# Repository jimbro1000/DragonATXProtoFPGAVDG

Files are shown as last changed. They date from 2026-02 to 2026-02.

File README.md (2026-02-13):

# Dragon ATX Prototype FPGA VDG

This repository contains the KiCad project files
to produce the VDG component board for my
ATX Prototype backplane.

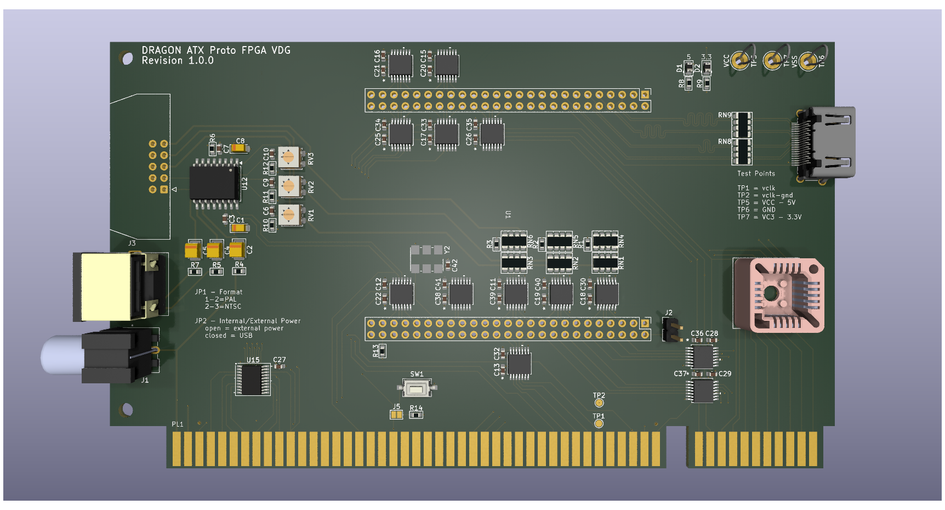
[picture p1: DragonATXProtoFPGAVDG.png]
Render of PCB top


This design requires the ATX backplane board in order 
to operate
See https://github.com/jimbro1000/DragonATXProto

## Notes

Revision 1 includes a more modern RGB fed modulator
design that removes a significant problem in the 
form of the old LM1889 modulator. The board also
provides the mounting points for the various mezzanine
boards that have been previously developed. If the
mezzanine option is to be used the rest of the card
should be left unpopulated

This design has been completed using KiCad 9. Earlier
versions of KiCad are not compatible

## Memory Map

| Address Range | Usage | Notes |
|:--- |:----- |:----- |
| $0000 - $7FFF | Lower 32K RAM page | Can be remapped to the upper 32K using P1 under RAM/ROM memory map type |
| $8000 - $9FFF | Lower system ROM (R0) | The last 16 bytes are mapped to $FFF0 - $FFFF |
| $A000 - $BFFF | Upper system ROM (R1) | |
| $C000 - $FF00 | External ROM (R2) | |
| $C000 - $FF00 | Upper 32K RAM page | Under RAM only memory map type |
| $FF00 - $FFEF | SAM registers and Peripheral IO |
| $FF00 - $FF1F | PIA 0 & Serial port |
| $FF20 - $FF23 | PIA 1 |
| $FF24 - $FF27 | PIA 1b | video expansion slot |
| $FF28 - $FF2F | PIA 1c and 1d | audio expansion slot |
| $FF30 - $FF37 | PIA 1e and 1f | expansion slot 3 |
| $FF38 - $FF3F | PIA 1g and 1h | expansion slot 4 |
| $FF40 - $FF5F | PIA 2 | external |
| $FF60 - $FFBF | reserved |
| $FF90 | Set compatible mode | bit 7 (1) |
| $FF91 | Set task id | bits 0..2 (2)(3) |
| $FF92 | IRQ control bits | (4) |
| $FF93 | FIRQ control bits | (4) |
| $FF94 | MSB of timer |
| $FF95 | LSB of timer |
| $FFA0 | Select RAM paging register | Registers are selected for the current task only |
| $FFA1 | Upper byte of page register | |
| $FFA2 | Lower byte of page register | Writing to the lower byte commits changes to the selected register |
| $FFC0 - $FFDF | SAM |
| $FFE0 - $FFEF | reserved |
| $FFF0 - $FFFF | CPU vectors |

1. Compatibility mode forces the SAMx to behave as an original MC6883 SAM. Setting the bit to 1 turns compatibility on, clearing the bit enables the additional SAMx features. The other bits of the register are unused.

2. Tasks are identified by 3 bits - bits 0 to 2, 000 = task 0 (typically reserved for the operating system), 001 = task 1, 010 = task 2, 011 = task 3, 100 = task 4. (task ids 101 and 110 are reserved for VDG and library pages, 111 is associated with unallocated pages).

3. Bit 5 is used to specify the resolution of the timer, clearing the bit used a slow timer, setting the bit uses a fast timer.

4. The SAMx can generate interrupts according to the bit masks set for IRQ and FIRQ. The only bit defined at the moment is bit 5 and is triggered by the timer (counting down to 0). If the bit is cleared the SAMx will not generate an interrupt, if set the interrupt will be generated against the chosen interrupt line ($FF92 for IRQ, $FF93 for FIRQ). It is currently possible to specify an interrupt on both lines, in this situation FIRQ will be used.

5. In the RAM type memory map the paging for any of the registers can be set to bank of the ROM, in the RAM/ROM type memory map the R0 and R1 blocks need to behave differently. R0 at $8000 is mapped in 4 blocks to $00000 of the ROM by default, R1 is mapped to $A000 in 4 blocks at $02000. R2 is bound exclusively to the cartridge port ROM space at $C000, there is no mechanism to map this to a ROM bank. In RAM mode R2 can be mapped to a RAM or ROM bank but if a cartridge is fitted the paging is ignored and the cartridge ROM is used instead.

### Expanded Memory

| Address Range | Notes |
|:--- |:----- |
| $000000 - $00FFFF | CPU addressable range |
| $000000 - $01FFFF | VDG addressable range |
| $000000 - $1FFFFF | Maximum onboard paged RAM |
| $000000 - $080000 | Maximum onboard paged ROM |

## Design

Unlike previous iterations that attempt to simply
replicate the original 6847 using CPLD hardware, this
design is aimed at a full upgrade and replacement for 
the 6847 and 6883. By combining the functionality of
the two chips are significant saving in complexity is
achieved. There is no longer a requirement to 
artificially synchronise the video against the CPU
clock cycle, this is inherent as the video clock is
tied directly to the cpu clock.

## SAM upgrades

The SAM replacement is based around the work done by
Ciaran Anscomb to upgrade the SAM to include RAM paging.
His design extended to 512KB which, while "adequate", 
is wasteful of the target FPGA device which includes
16MB of RAM. Of that 16MB only 2MB is directly accessed
as a single block. The 2MB is 16bit wide (technically 4MB)
but accessing both halves of the RAM adds extra complexity
to the read/write cycle, just using one half is definitely
simpler.

### SAM Registers ###

As a result of the SAM having full access to the databus the
internal registers can now be fully programmed with a single
write operation (or per bit if required). The registers are
expanded as necessary, for example the video base address is
extended to allow addressing of a much larger memory space,
and the introduction of new registers for process and memory
mapping.

#### Programmable Registers ####

| Register | Size | Usage |
| --- | ---- | ----- |
| V | 3 bits | Video addressing mode - 4 bits in expanded mode - the extra bit is ignored unless the VDG compatibility mode is disabled |
| F | 7 bits | Video base addressing multiples of 512 bytes - 8 bits in expanded mode, after a vertical sync the VDG address counter bits 9 - 15 are loaded with the value held in F, the lower 8 bits are set to 0. In expanded mode bits 9-16 are loaded from F |
| P | 1 bit | RAM/ROM mode page register |
| R | 2 bits | CPU speed control |
| M | 2 bits | Used to define Memory size in original SAM, unused here |
| TY | 1 bit | Memory Map Type |

#### Internal Registers

| Register | Size | Usage |
| --- | ---- | ----- |
| C | 7 bits | DRAM refresh counter - unused here |
| B | 16 bits | VDG address counter - 17 bits in expanded mode |
| N0..4x8 | 9 bits | Page Allocation Table (1) |
| NVx16 | 9 bits | Video Page Allocation Table (2) |
| Ox256 | 3 bits | Page Owner Table (3) |
| T | 3 bits | Current Task ID |
| VL | 1 bit | Video Page Lock (4) |

1. Each task has a set of 8 registers, each 9 bits in length. The MSB of each indicates
if the value is referencing RAM (0) or ROM (1). Each register defines an 8K address window
and what page of memory it is mapped to. Only one set of N registers is addressable at any
time dependent on the current task ID.

2. The Video "task" has its own set of page allocation registers and this extends to a 
total addressable space of 128K. The Video page registers are accessible to all tasks unless
the VL bit is set.

3. Each RAM page has a 4 bit identifier associated with, the value equates to one of
the task ids.

4. The Video Page lock restricts access to the video page registers to task id 0 (supervisor).
When set any attempts to modify the video page registers will be ignored.

### Memory Paging ###

The upgraded SAM provides MMU capabilities, both paging and process (page protection). With 256 8K pages in the address
space and each page can be allocated to RAM or ROM. Each process has its own page map.

Processes are either:

1. supervisor  
2. display
3. library (shared)
4. user process 1
5. user process 2
6. user process 3
7. user process 4

The shared process and display are used purely for identification of shared pages.

#### Display Process ####

The display process is used only for read operations by the VDG side of the clock cycle. The same pages can
be shared with the supervisor or a user process.

### Paging ###

Each process has its own map of 8K pages composed into the 64K memory space available directly to the CPU. The
only exception to this is the display process which has its own 128K memory space and is addressed only by the
VDG in this manner.

Each page has a permissions byte associated with it. The page is either unallocated (and can be acquired by any
process), or owned by one of the seven process ids. The display and library process pages are an exception and
can be shared between multiple processes.

The MMU maintains a page allocation table for all 256 available pages. Each process has its own address
translation map, only one map is presented to the CPU at a time, with the CPU address register translated
into the larger MMU address space.

### Rom Paging ###

Further to the available RAM pages the address map can reference pages from the ROM space. ROM pages are always
shared.

#### Rom Mapping At Cold Start ####

The MMU will always allocate the last page of the supervisor address space to the last ROM page to cover
the CPU vectors. The last ROM page should also include the bootstrap code to set the host into an operational
state.

At warm start the host will enter the supervisor process. Holding the host in reset for 2 seconds will
be treated as a cold start.

### Blitter ###

The blitter provides out-of-process memory copy in one of five operations:

1. Full page copy (8K copy from one page to another)
2. Continuous block copy (within process address space)
3. Shaped to continuous (within process address space)
4. Continuous to shaped (within process address space)
5. Shaped to shaped (within process address space)

All operations are defined by an origin, destination and byte length (maximum is 8K)

Shaped operations have two further parameters - width and gap. The width defines how many bytes in a row
are copied and the gap the number of bytes to skip to the next run of bytes

Copying can only be performed between pages allocated to the initiating process

Only a single blit operation can be performed at a time, all operations can be queued

The blit operates at the highest clock speed achievable by the RAM and SAM. Nominally this is 166MHz with a 3 cycle 
latency, the SAM operates at 28.6MHz and each byte copy takes 3 cycles. Effectively this means a copy rate of
8 bytes per CPU clock cycle (using interleaved access between CPU, VDG and Blitter) at regular 0.89MHz CPU
clock speeds. Running at a faster CPU speed would reduce the available slots for blit operations

The number of cycles for the blitter will be adjusted to suit the cpu and vdg clock speeds

A maximum copy speed can be achieved by halting the CPU and timing the blit start to the end of the vertical
display viewport. The slice allocation will reallocate CPU and VDG portions to the blitter - the result is
lightning fast block copy of ram. Page copy can run faster as it is guaranteed contiguous on both sides
meaning 64 bytes per copy cycle instead of 8 bytes. That is 128 CPU cycles (equivalent) to copy 8K at
page copy, 1024 cycles at shaped copy speeds but at the regular 0.895MHz that is still 0.001s to copy a
full 8K - in reality a shaped copy is likely to be much less than 8K in length. A regular high-res
screen is just 6K...

## VDG upgrades

The default operation mode for the VDG is full compatibility with the original MC6847. In practical
terms this means fixed display palettes (although these could still be modified through HDL source) and
standard resolutions.

With compatibility mode enabled all of the VDG control is as per the original device - external input for
Alpha/Semi, Alpha/Graphic, Graphic Mode, Inverse, Colour Set and Internal/External

With compatibility mode disabled the VDG expands control to a wide set of registers in the new
device (operated through the SAM for memory configuration and direct through a new memory
mapped device for mode). The default modes are still present but can be modified to suit, or
a new set of display modes can be used.

### VDG Registers

The upgraded VDG exists in mapped memory space, occupying 16 bytes. These form a set of registers
controlling how the video operates.

0. Video Mode Control - 8 bit flags for enabling features
1. Zero RAM Mode - left byte
2. Zero RAM Mode - right byte
3. Zero RAM Mode - palette
4. Palette - register select (0-47)
5. Palette - register data
6. Geometry - register select (0-7)
7. Geometry - register data
8. Sprite - sprite id select
9. Sprite - register select
10. Sprite - register data
11. Tile - tile id select
12. Tile - register select
13. Tile - register data
14. Counter - register select
15. Counter - register data

#### Video Mode Control

Bit 7 controls video display format, 1 = NTSC, 0 = PAL

Bit 6 controls the use of zero mode, 1 = enabled, 0 = disabled. Zero mode
is a zero ram mode that simply uses 2 static bytes of data per row, set 
using the zero ram mode registers.

Bit 5 enables tile mode. This is ignored in compatibility mode.

Bit 4 enables sprites. This is ignored in compatibility mode.

Bit 3 enables zero mode as an overlay. In this state the background colour is
always transparent.

Bit 2 enables the extended graphic modes. This is ignored in compatibility
mode.

Bit 1 is reserved for future use.

Bit 0 controls compatibility. 1 = extended options enabled, 0 = 6847
compatible.

#### Zero RAM Mode

Zero RAM mode operates without the need to load any data from RAM, combined
with a suitable ROM image this means the host system can display useful
diagnostic data without the need for working RAM. Zero RAM can also be 
enabled as an overlay over other display modes.

In Zero mode the display resolution is 16 pixels wide. The left hand side
of the display is register 1, the right hand side is register 2.

Register 1 is the first 8 bits of each row, the same data is displayed
vertically for the entire viewport unless changed mid-frame. Register is the final
8 bits of each row with the same behaviour vertically.

Register 3 controls the colour of the display, the first 4 bits define the
foreground, the last 8 bits define the background. In overlay mode the background
is always transparent.

The colours are each 4 bit TTL RGB with half bright. In the case of black the half
bright equivalent is a darker shade of grey than white with half bright.

#### Palette Control

The VDG supports 24 different programmable entries in its palette. Each one is 12 bits
of RGB and require two palette registers to access each one. Even palette registers represent 
the upper 4 bits (red) of each entry, odd palette entries represent the lower 8 bits (green and
blue) of each entry.

The first palette register (4) selects which palette entry is being referenced. With two
registers per entry the value must be multiplied by two for each entry.

The second palette register (5) defines the data of the selected palette entry.

#### Geometry Control

In the extended modes the display geometry can be modified, significantly increasing the
flexibility of thos modes.

VDG Register 6 selects which of the geometry registers is active. VDG Register 7 accesses 
the value of each.

0. Upper 2 bits of the viewport X position on screen.
1. Lower 8 bits of the viewport X position.
2. Upper 1 bit of the viewport y position.
3. Lower 8 bits of the viewport y position.
4. Viewport width (in bytes, 0-63).
5. Viewport height (in rows, 0-255).
6. Upper 1 bit of the display height (in rows).
7. Lower 8 bits of the display height.

More geometry registers may be added as new features are introduced.

#### Sprite Control

Sprites are relatively complex objects in this system. Each sprite Id can be a graphic
definition, or it can be a path object that sets how the sprite moves

VDG Register 8 selects which sprite Id is active, VDG Register 9 selects the address of the object
data. Each sprite object can be up to 255 bytes long.

VDG Register 10 access the data of the object.

#### Tile Control

Tiles are handled in much the same way as sprites for the purposes of defining them.

VDG Register 11 selects which tile Id is referenced (0-255). VDG Register 12 sets
the address within the selected tile object. VDG Register 13 accesses the tile data at
the given address.

#### Counters

A small number of counters can be defined to automatically trigger actions based on
the row or column of the current display frame.

VDG Register 14 selects which counter register is active. VDG Register 15
accesses the data for the selected counter.

### Display Layers

The display presented to the screen is composed of a series of layers.

Top most are sprites, these always have a transparency and appear over all
other graphical detail.

The next layer down is the "regular" bitmap graphic mode. If no other layers
are enabled the "0" colour will be visible, otherwise it will be transparent.

Below the bitmap mode lies the zero mode. As with the bitmap mode if tile mode
is not enabled the background colour is visible, otherwise it will be transparent.

The lowest layer is the tile mode. This has no transparency and every position
on the display must have a tile.

The composition of layers in this way offers the maximum flexibility from the
capabilities of the enhanced VDG.

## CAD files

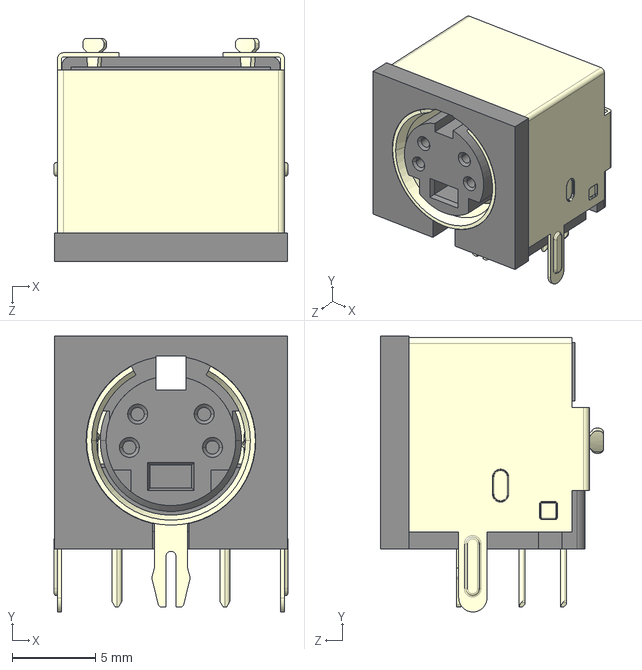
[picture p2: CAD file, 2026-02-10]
Library.3dModels/MD-40SM.step
14.1 x 16.6 x 13.4 mm

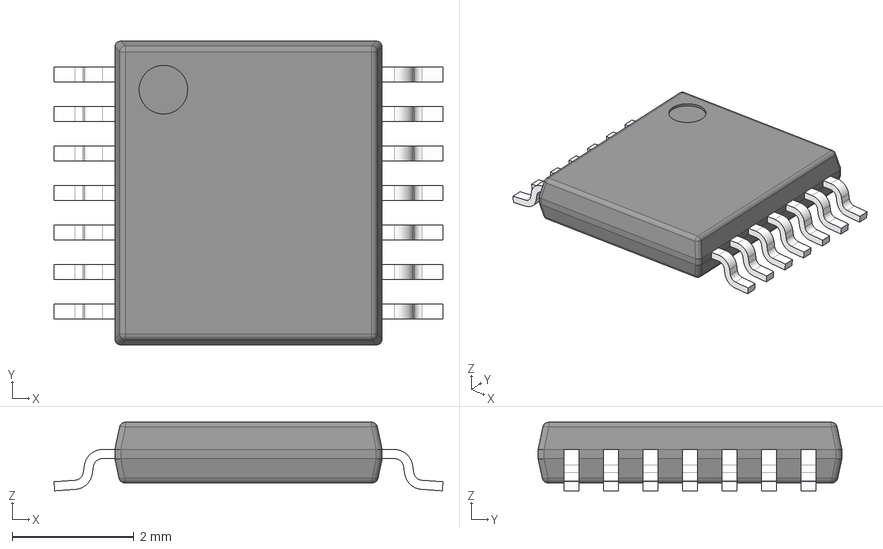
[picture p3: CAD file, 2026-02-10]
Library.3dModels/PW0014A.stp
6.40 x 5.00 x 1.13 mm
BODY-TSSOP
LEAD-TSSOP x 14
PIN1

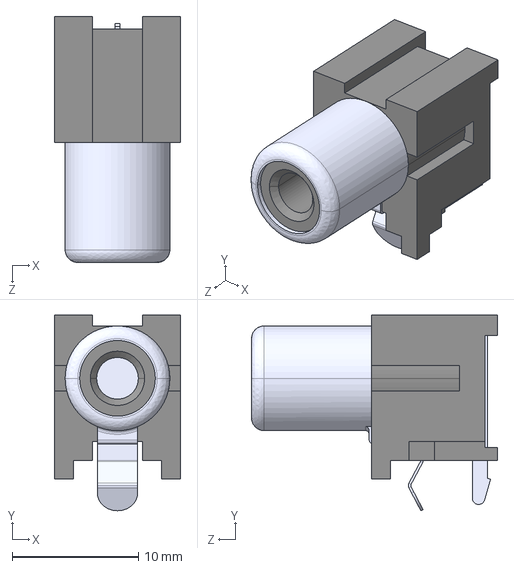
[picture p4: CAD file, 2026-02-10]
Library.3dModels/RCJ-041.step
10.0 x 15.5 x 19.5 mm

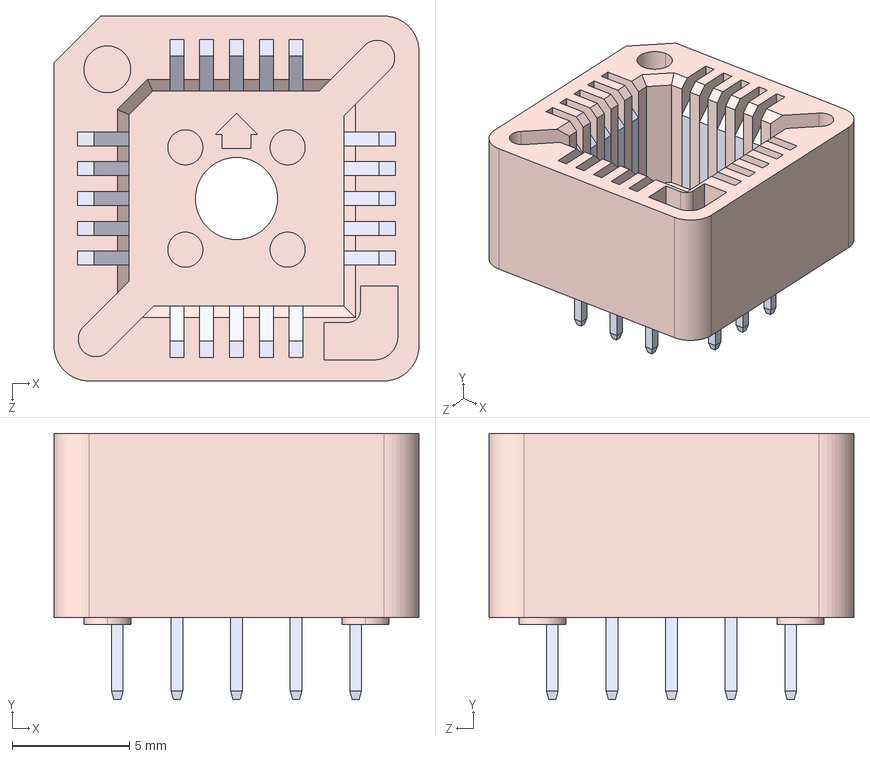
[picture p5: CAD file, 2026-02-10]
Library.3dModels/PLCC-20-R.STEP
15.6 x 11.4 x 15.6 mm

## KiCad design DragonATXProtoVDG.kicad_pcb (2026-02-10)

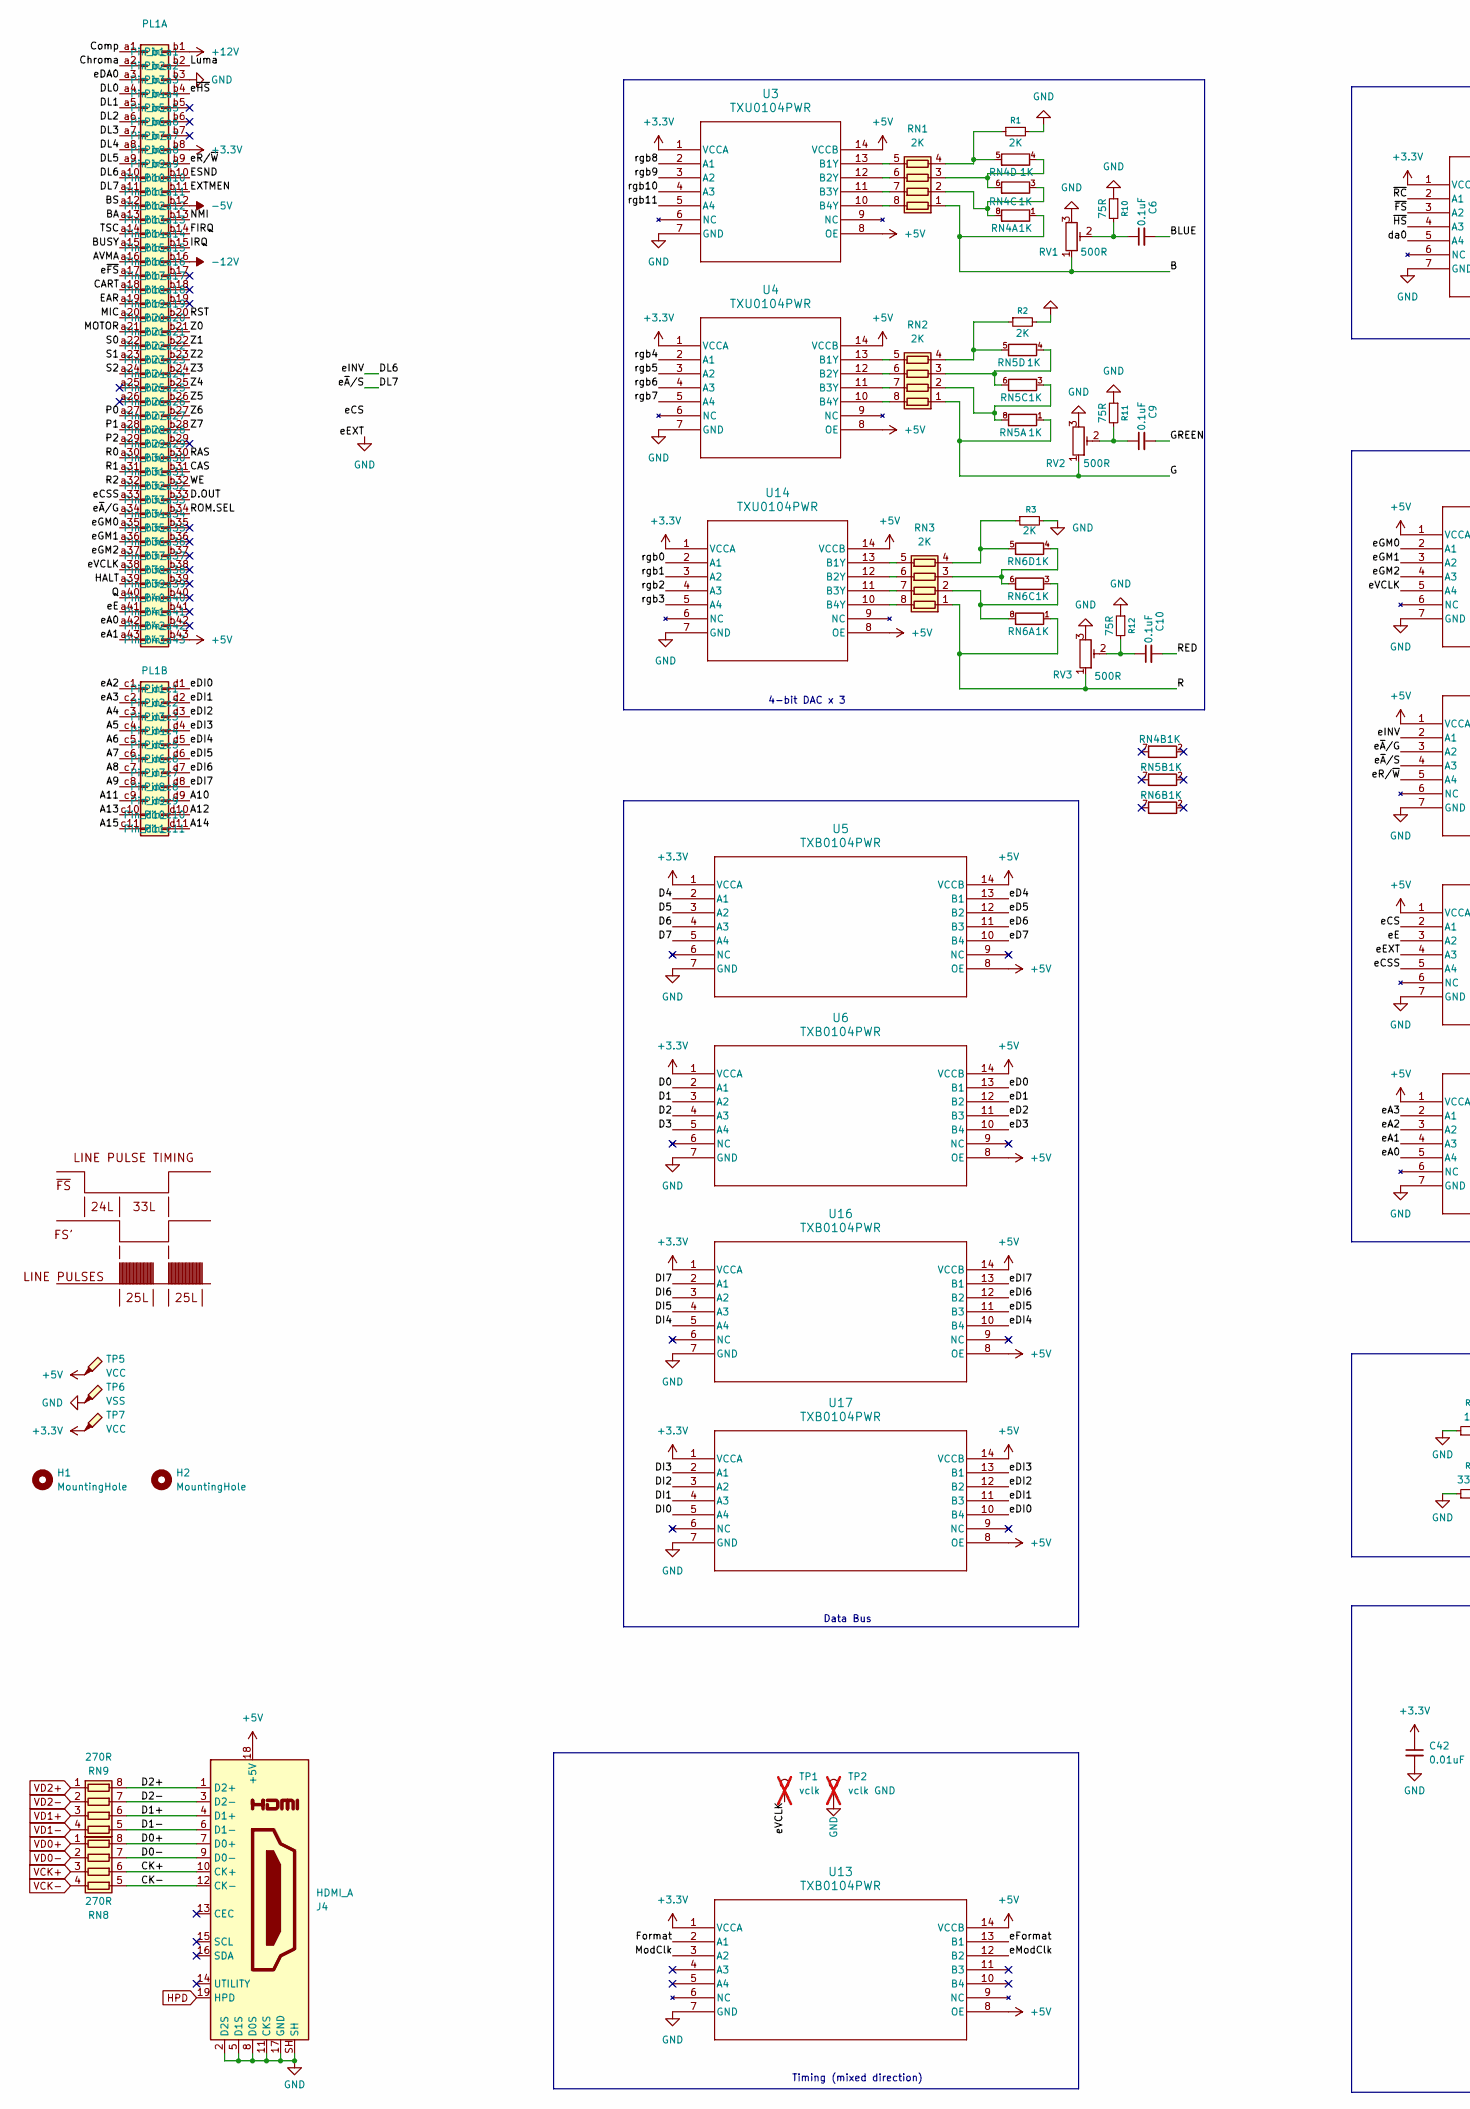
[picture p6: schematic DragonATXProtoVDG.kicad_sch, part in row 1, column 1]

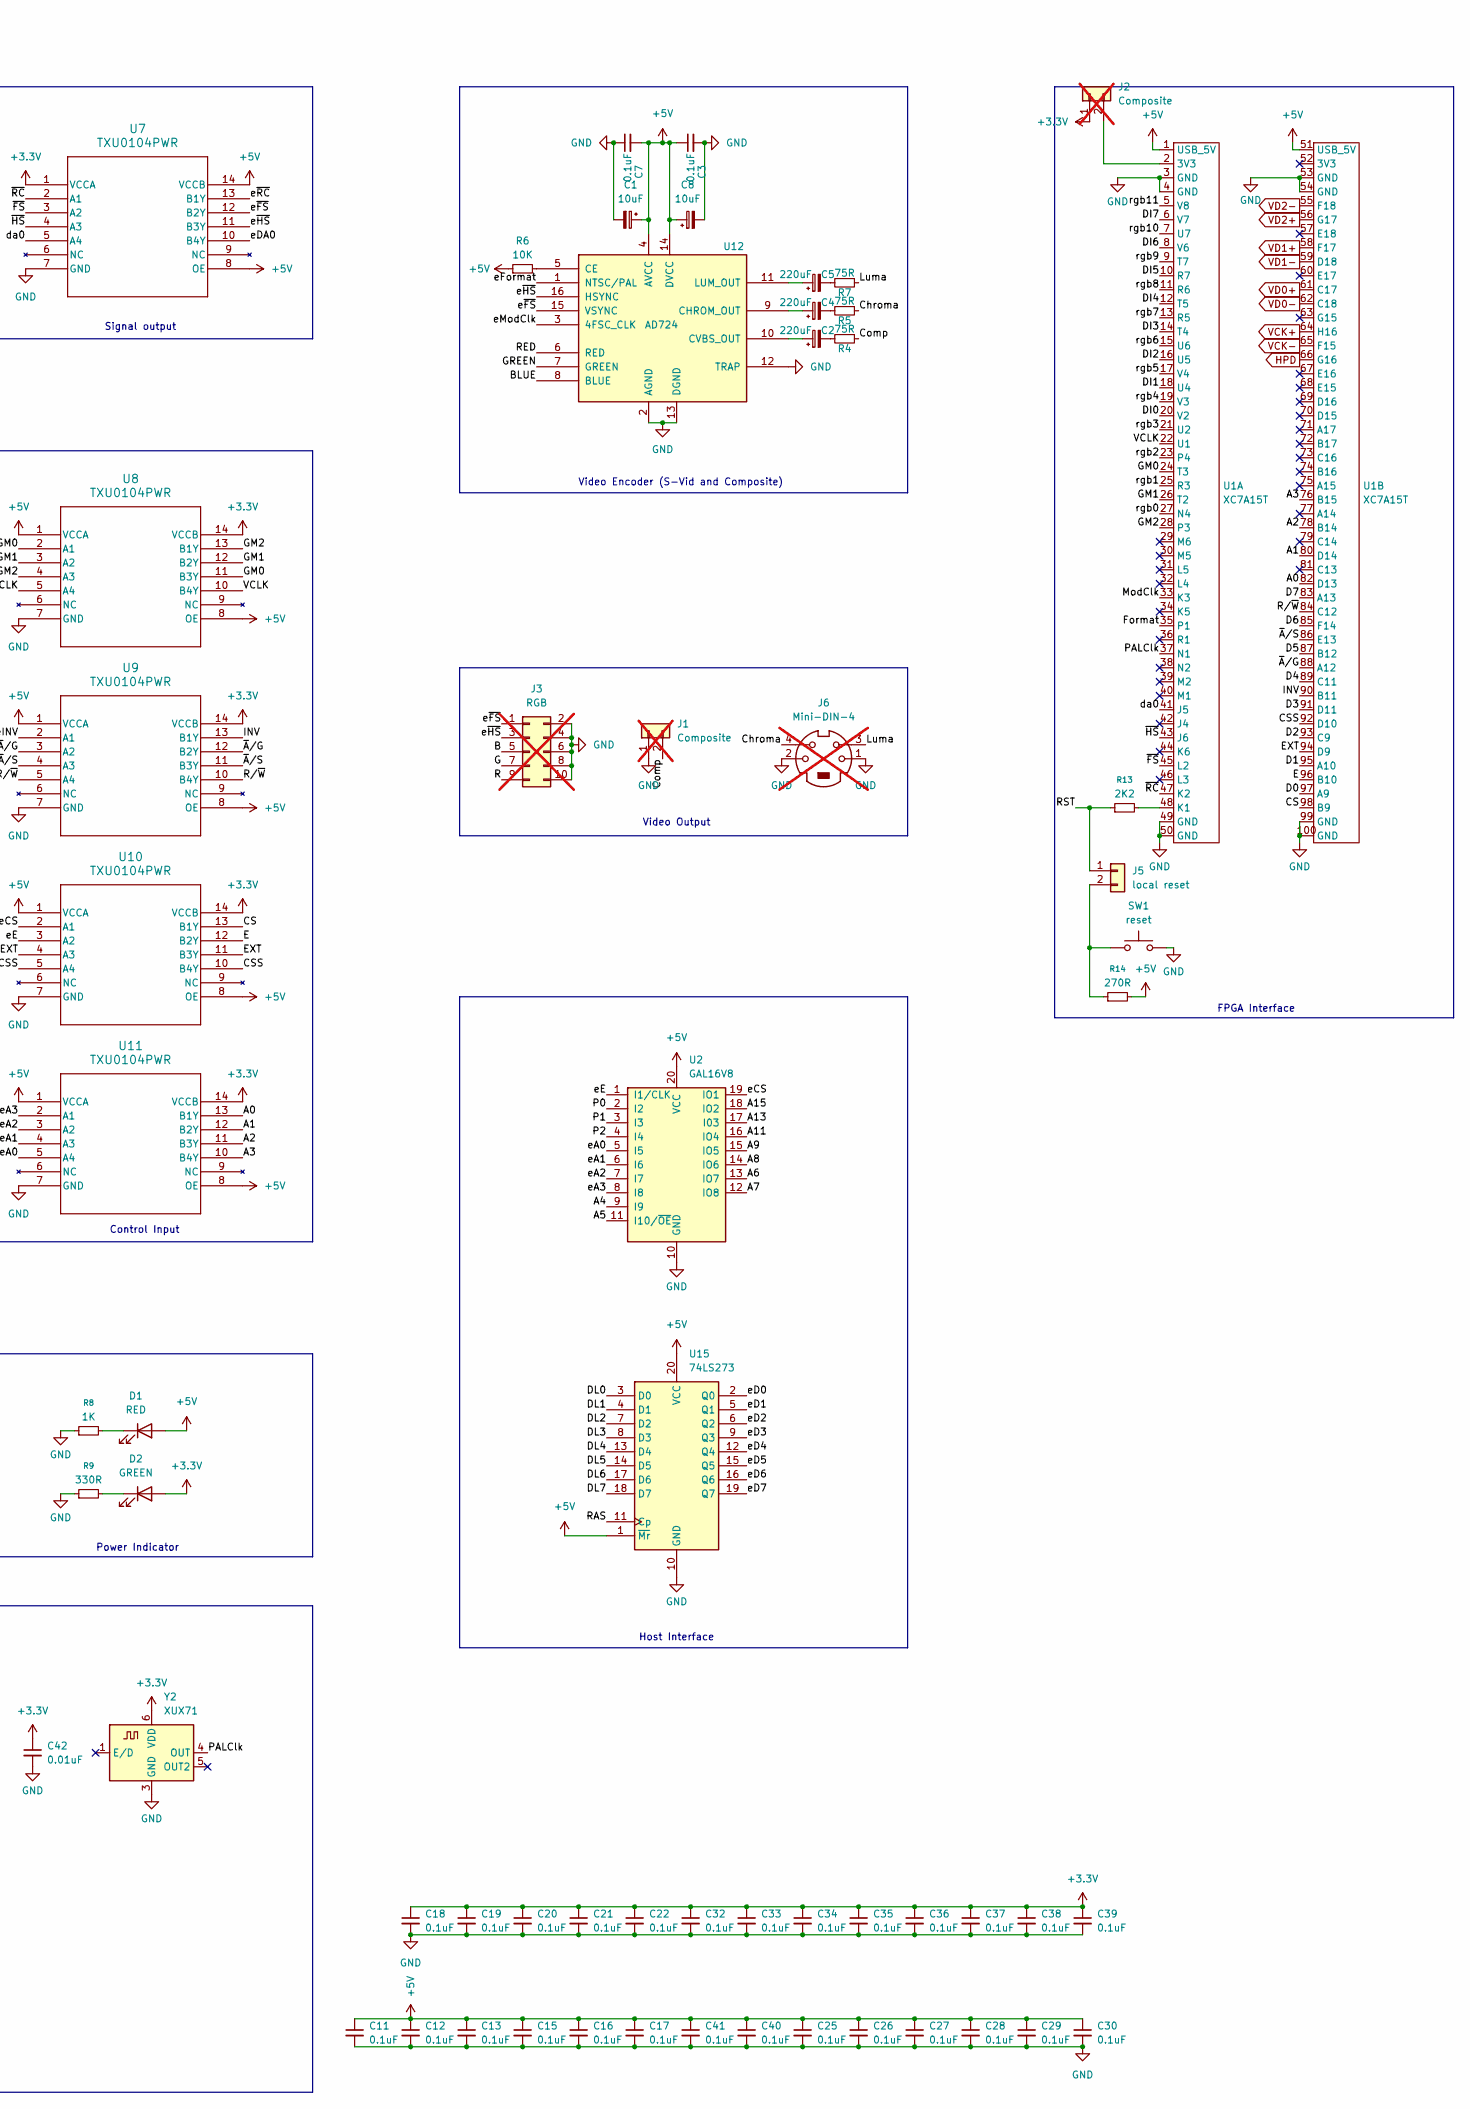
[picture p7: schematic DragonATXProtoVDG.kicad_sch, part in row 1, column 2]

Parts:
C1, C8: 10uF; CP_EIA-3216-18_Kemet-A; DigiKey 399-3683-1-ND
C2, C4, C5: 220uF; CP_EIA-3528-21_Kemet-B; DigiKey 399-T490B227M006ATE300CT-ND
C3, C6, C7, C9, C10, C11, C12, C13, C15, C16, C17, C18, C19, C20, C21, C22, C25, C26, C27, C28, C29, C30, C32, C33, C34, C35, C36, C37, C38, C39, C40, C41: 0.1uF; C_0603_1608Metric; LCSC C14663
C42: 0.01uF; C_0603_1608Metric; LCSC C57112
D1: RED; D_0805_2012Metric; LCSC C84256
D2: GREEN; D_0805_2012Metric; LCSC C2297
H1, H2: MountingHole; MountingHole_3.2mm_M3
J1: Composite; CUI_RCJ-041; not fitted
J2: Composite; PinHeader_1x02_P2.54mm_Vertical; not fitted
J3: RGB; IDC-Header_2x05_P2.54mm_Latch_Horizontal; not fitted
J4: HDMI_A; HDMI_A_Amphenol_10029449-x01xLF_Horizontal
J5: local reset; SolderJumper-2_P1.3mm_Open_Pad1.0x1.5mm
J6: Mini-DIN-4; MINI-DIN-4; not fitted
PL1: Card_Edge
R1, R2, R3: 2K; R_0603_1608Metric; LCSC C22975
R4, R5, R7: 75R; R_0603_1608Metric; DigiKey RMCF0603FT75R0CT-ND
R6: 10K; R_0603_1608Metric; DigiKey RMCF0603JT10K0CT-ND
R8: 1K; R_0603_1608Metric; DigiKey RMCF0603FT1K00CT-ND
R9: 330R; R_0603_1608Metric; DigiKey RMCF0603JT330RCT-ND
R10, R11, R12: 75R; R_0603_1608Metric; LCSC C4275
R13: 2K2; R_0603_1608Metric; DigiKey RMCF0603FT1K00CT-ND
R14: 270R; R_0603_1608Metric; DigiKey RMCF0603FT1K00CT-ND
RN1, RN2, RN3: 2K; R_Array_Convex_4x1206; DigiKey 13-YC324-FK-072KLCT-ND
RN4, RN5, RN6: 1K; R_Array_Convex_4x1206; DigiKey 13-YC324-FK-071KLCT-ND
RN8, RN9: 270R; R_Array_Convex_4x1206; DigiKey 13-YC324-FK-072KLCT-ND
RV1, RV2, RV3: 500R; Potentiometer_Bourns_3314J_Vertical; DigiKey 3314J-501ECT-ND
SW1: reset; SW_Tactile_SPST_NO_Straight_CK_PTS636Sx25SMTRLFS
TP1: vclk; TestPoint_Pad_D1.5mm; not fitted
TP2: vclk GND; TestPoint_Pad_D1.5mm; not fitted
TP5, TP7: VCC; TestPoint_Loop_D3.80mm_Drill2.0mm
TP6: VSS; TestPoint_Loop_D3.80mm_Drill2.0mm
U1: XC7A15T; QMTECH_XC7A15T
U2: GAL16V8; PLCC-20_THT-Socket
U3, U4, U7, U8, U9, U10, U11, U14: TXU0104PWR; TSSOP_0104PWR; DigiKey 296-TXU0104PWRCT-ND
U5, U6, U13, U16, U17: TXB0104PWR; TSSOP_0104PWR; DigiKey 296-21929-1-ND
U12: AD724; SOIC-16W_7.5x10.3mm_P1.27mm
U15: 74LS273; TSSOP-20_4.4x6.5mm_P0.65mm; DigiKey 1727-7301-1-ND
Y2: XUX71; Oscillator_SMD_IDT_JU6-6_7.0x5.0mm_P2.54mm; Mouser 972-XLH735004433619X
Z1: LINE_PULSE_DIAGRAM

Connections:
+3.3V: C18.1, C19.1, C20.1, C21.1, C22.1, C32.1, C33.1, C34.1, C35.1, C36.1, C37.1, C38.1, C39.1, C42.1, D2.2 (A), J2.1, PL1.b8, TP7.1, U3.1 (VCCA), U4.1 (VCCA), U5.1 (VCCA), U6.1 (VCCA), U7.1 (VCCA), U8.14 (VCCB), U9.14 (VCCB), U10.14 (VCCB), U11.14 (VCCB), U13.1 (VCCA), U14.1 (VCCA), U16.1 (VCCA), U17.1 (VCCA), Y2.6 (VDD)
+5V: C1.1, C3.1, C7.2, C8.1, C11.1, C12.1, C13.1, C15.1, C16.1, C17.1, C25.1, C26.1, C27.1, C28.1, C29.1, C30.1, C40.1, C41.1, D1.2 (A), J4.18 (+5V), PL1.b43, R6.1, R14.2, TP5.1, U1.1 (USB_5V), U1.51 (USB_5V), U2.20 (VCC), U3.8 (OE), U3.14 (VCCB), U4.8 (OE), U4.14 (VCCB), U5.8 (OE), U5.14 (VCCB), U6.8 (OE), U6.14 (VCCB), U7.8 (OE), U7.14 (VCCB), U8.1 (VCCA), U8.8 (OE), U9.1 (VCCA), U9.8 (OE), U10.1 (VCCA), U10.8 (OE), U11.1 (VCCA), U11.8 (OE), U12.4 (AVCC), U12.14 (DVCC), U13.8 (OE), U13.14 (VCCB), U14.8 (OE), U14.14 (VCCB), U15.1 (~Mr), U15.20 (VCC), U16.8 (OE), U16.14 (VCCB), U17.8 (OE), U17.14 (VCCB)
+12V: PL1.b1
-5V: PL1.b12
-12V: PL1.b16
/A0: U1.82 (D13), U11.13 (B1Y)
/A1: U1.80 (D14), U11.12 (B2Y)
/A2: U1.78 (B14), U11.11 (B3Y)
/A3: U1.76 (B15), U11.10 (B4Y)
/A4: PL1.c3, U2.9 (I9)
/A5: PL1.c4, U2.11 (I10/~OE)
/A6: PL1.c5, U2.13 (IO7)
/A7: PL1.c6, U2.12 (IO8)
/A8: PL1.c7, U2.14 (IO6)
/A9: PL1.c8, U2.15 (IO5)
/A10: PL1.d9
/A11: PL1.c9, U2.16 (IO4)
/A12: PL1.d10
/A13: PL1.c10, U2.17 (I03)
/A14: PL1.d11
/A15: PL1.c11, U2.18 (IO2)
/AVMA: PL1.a16
/B: J3.5, RN1.1 (R1.1), RN4.1 (R1.1), RV1.1
/BA: PL1.a13
/BLUE: C6.2, U12.8 (BLUE)
/BS: PL1.a12
/BUSY: PL1.a15
/CART: PL1.a18
/CAS: PL1.b31
/CK+: J4.10 (CK+), RN8.6 (R3.2)
/CK-: J4.12 (CK-), RN8.5 (R4.2)
/CS: U1.98 (B9), U10.13 (B1Y)
/CSS: U1.92 (D10), U10.10 (B4Y)
/Chroma: J6.4, PL1.a2, R5.1
/Comp: J1.2, PL1.a1, R4.1
/D0: U1.97 (A9), U6.2 (A1)
/D0+: J4.7 (D0+), RN8.8 (R1.2)
/D0-: J4.9 (D0-), RN8.7 (R2.2)
/D1: U1.95 (A10), U6.3 (A2)
/D1+: J4.4 (D1+), RN9.6 (R3.2)
/D1-: J4.6 (D1-), RN9.5 (R4.2)
/D2: U1.93 (C9), U6.4 (A3)
/D2+: J4.1 (D2+), RN9.8 (R1.2)
/D2-: J4.3 (D2-), RN9.7 (R2.2)
/D3: U1.91 (D11), U6.5 (A4)
/D4: U1.89 (C11), U5.2 (A1)
/D5: U1.87 (B12), U5.3 (A2)
/D6: U1.85 (F14), U5.4 (A3)
/D7: U1.83 (A13), U5.5 (A4)
/D.OUT: PL1.b33
/DI0: U1.20 (V2), U17.5 (A4)
/DI1: U1.18 (U4), U17.4 (A3)
/DI2: U1.16 (U5), U17.3 (A2)
/DI3: U1.14 (T4), U17.2 (A1)
/DI4: U1.12 (T5), U16.5 (A4)
/DI5: U1.10 (R7), U16.4 (A3)
/DI6: U1.8 (V6), U16.3 (A2)
/DI7: U1.6 (V7), U16.2 (A1)
/DL0: PL1.a4, U15.3 (D0)
/DL1: PL1.a5, U15.4 (D1)
/DL2: PL1.a6, U15.7 (D2)
/DL3: PL1.a7, U15.8 (D3)
/DL4: PL1.a8, U15.13 (D4)
/DL5: PL1.a9, U15.14 (D5)
/DL6: PL1.a10, U9.2 (A1), U15.17 (D6)
/DL7: PL1.a11, U9.4 (A3), U15.18 (D7)
/E: U1.96 (B10), U10.12 (B2Y)
/EAR: PL1.a19
/ESND: PL1.b10
/EXT: U1.94 (D9), U10.11 (B3Y)
/EXTMEN: PL1.b11
/FIRQ: PL1.b14
/Format: U1.35 (P1), U13.2 (A1)
/G: J3.7, RN2.1 (R1.1), RN5.1 (R1.1), RV2.1
/GM0: U1.24 (T3), U8.11 (B3Y)
/GM1: U1.26 (T2), U8.12 (B2Y)
/GM2: U1.28 (P3), U8.13 (B1Y)
/GREEN: C9.2, U12.7 (GREEN)
/HALT: PL1.a39
/INV: U1.90 (B11), U9.13 (B1Y)
/IRQ: PL1.b15
/Luma: J6.3, PL1.b2, R7.1
/MIC: PL1.a20
/MOTOR: PL1.a21
/ModClk: U1.33 (K3), U13.3 (A2)
/NMI: PL1.b13
/P0: PL1.a27, U2.2 (I2)
/P1: PL1.a28, U2.3 (I3)
/P2: PL1.a29, U2.4 (I4)
/PALClk: U1.37 (N1), Y2.4 (OUT)
/Q: PL1.a40
/R: J3.9, RN3.1 (R1.1), RN6.1 (R1.1), RV3.1
/R0: PL1.a30
/R1: PL1.a31
/R2: PL1.a32
/RAS: PL1.b30, U15.11 (Cp)
/RED: C10.2, U12.6 (RED)
/ROM.SEL: PL1.b34
/RST: J5.1, PL1.b20, R13.1
/R/~W: U1.84 (C12), U9.10 (B4Y)
/S0: PL1.a22
/S1: PL1.a23
/S2: PL1.a24
/TSC: PL1.a14
/VCLK: U1.22 (U1), U8.10 (B4Y)
/WE: PL1.b32
/Z0: PL1.b21
/Z1: PL1.b22
/Z2: PL1.b23
/Z3: PL1.b24
/Z4: PL1.b25
/Z5: PL1.b26
/Z6: PL1.b27
/Z7: PL1.b28
/da0: U1.41 (J5), U7.5 (A4)
/eA0: PL1.a42, U2.5 (I5), U11.5 (A4)
/eA1: PL1.a43, U2.6 (I6), U11.4 (A3)
/eA2: PL1.c1, U2.7 (I7), U11.3 (A2)
/eA3: PL1.c2, U2.8 (I8), U11.2 (A1)
/eCS: U2.19 (IO1), U10.2 (A1)
/eCSS: PL1.a33, U10.5 (A4)
/eD0: U6.13 (B1), U15.2 (Q0)
/eD1: U6.12 (B2), U15.5 (Q1)
/eD2: U6.11 (B3), U15.6 (Q2)
/eD3: U6.10 (B4), U15.9 (Q3)
/eD4: U5.13 (B1), U15.12 (Q4)
/eD5: U5.12 (B2), U15.15 (Q5)
/eD6: U5.11 (B3), U15.16 (Q6)
/eD7: U5.10 (B4), U15.19 (Q7)
/eDA0: PL1.a3, U7.10 (B4Y)
/eDI0: PL1.d1, U17.10 (B4)
/eDI1: PL1.d2, U17.11 (B3)
/eDI2: PL1.d3, U17.12 (B2)
/eDI3: PL1.d4, U17.13 (B1)
/eDI4: PL1.d5, U16.10 (B4)
/eDI5: PL1.d6, U16.11 (B3)
/eDI6: PL1.d7, U16.12 (B2)
/eDI7: PL1.d8, U16.13 (B1)
/eE: PL1.a41, U2.1 (I1/CLK), U10.3 (A2)
/eFormat: U12.1 (NTSC/PAL), U13.13 (B1)
/eGM0: PL1.a35, U8.2 (A1)
/eGM1: PL1.a36, U8.3 (A2)
/eGM2: PL1.a37, U8.4 (A3)
/eModClk: U12.3 (4FSC_CLK), U13.12 (B2)
/eR/~W: PL1.b9, U9.5 (A4)
/eVCLK: PL1.a38, TP1.1, U8.5 (A4)
/e~A/G: PL1.a34, U9.3 (A2)
/e~FS: J3.1, PL1.a17, U7.12 (B2Y), U12.15 (VSYNC)
/e~HS: J3.3, PL1.b4, U7.11 (B3Y), U12.16 (HSYNC)
/e~RC: U7.13 (B1Y)
/rgb0: U1.27 (N4), U14.2 (A1)
/rgb1: U1.25 (R3), U14.3 (A2)
/rgb2: U1.23 (P4), U14.4 (A3)
/rgb3: U1.21 (U2), U14.5 (A4)
/rgb4: U1.19 (V3), U4.2 (A1)
/rgb5: U1.17 (V4), U4.3 (A2)
/rgb6: U1.15 (U6), U4.4 (A3)
/rgb7: U1.13 (R5), U4.5 (A4)
/rgb8: U1.11 (R6), U3.2 (A1)
/rgb9: U1.9 (T7), U3.3 (A2)
/rgb10: U1.7 (U7), U3.4 (A3)
/rgb11: U1.5 (V8), U3.5 (A4)
/~A/G: U1.88 (A12), U9.12 (B2Y)
/~A/S: U1.86 (E13), U9.11 (B3Y)
/~FS: U1.45 (L2), U7.3 (A2)
/~HS: U1.43 (J6), U7.4 (A3)
/~RC: U1.47 (K2), U7.2 (A1)
GND: C1.2, C3.2, C7.1, C8.2, C11.2, C12.2, C13.2, C15.2, C16.2, C17.2, C18.2, C19.2, C20.2, C21.2, C22.2, C25.2, C26.2, C27.2, C28.2, C29.2, C30.2, C32.2, C33.2, C34.2, C35.2, C36.2, C37.2, C38.2, C39.2, C40.2, C41.2, C42.2, J1.1, J3.2, J3.4, J3.6, J3.8, J3.10, J4.2 (D2S), J4.5 (D1S), J4.8 (D0S), J4.11 (CKS), J4.17 (GND), J4.SH, J6.1, J6.2, PL1.b3, R1.2, R2.2, R3.2, R8.1, R9.1, R10.1, R11.1, R12.1, RV1.3, RV2.3, RV3.3, SW1.2, TP2.1, TP6.1, U1.3 (GND), U1.4 (GND), U1.49 (GND), U1.50 (GND), U1.53 (GND), U1.54 (GND), U1.99 (GND), U1.100 (GND), U2.10 (GND), U3.7 (GND), U4.7 (GND), U5.7 (GND), U6.7 (GND), U7.7 (GND), U8.7 (GND), U9.7 (GND), U10.4 (A3), U10.7 (GND), U11.7 (GND), U12.2 (AGND), U12.12 (TRAP), U12.13 (DGND), U13.7 (GND), U14.7 (GND), U15.10 (GND), U16.7 (GND), U17.7 (GND), Y2.3 (GND)
HPD: J4.19 (HPD), U1.66 (G16)
unnamed: C2.2, R4.2
unnamed: C4.2, R5.2
unnamed: C5.2, R7.2
unnamed: C6.1, R10.2, RV1.2
unnamed: C9.1, R11.2, RV2.2
unnamed: C10.1, R12.2, RV3.2
unnamed: D1.1 (K), R8.2
unnamed: D2.1 (K), R9.2
unnamed: J2.2, U1.2 (3V3)
unnamed: J5.2, R14.1, SW1.1
unnamed: RN1.8 (R1.2), U3.10 (B4Y)
unnamed: RN1.2 (R2.1), RN4.3 (R3.1), RN4.8 (R1.2)
unnamed: RN1.7 (R2.2), U3.11 (B3Y)
unnamed: RN1.3 (R3.1), RN4.4 (R4.1), RN4.6 (R3.2)
unnamed: RN1.6 (R3.2), U3.12 (B2Y)
unnamed: R1.1, RN1.4 (R4.1), RN4.5 (R4.2)
unnamed: RN1.5 (R4.2), U3.13 (B1Y)
unnamed: RN2.8 (R1.2), U4.10 (B4Y)
unnamed: RN2.2 (R2.1), RN5.3 (R3.1), RN5.8 (R1.2)
unnamed: RN2.7 (R2.2), U4.11 (B3Y)
unnamed: RN2.3 (R3.1), RN5.4 (R4.1), RN5.6 (R3.2)
unnamed: RN2.6 (R3.2), U4.12 (B2Y)
unnamed: R2.1, RN2.4 (R4.1), RN5.5 (R4.2)
unnamed: RN2.5 (R4.2), U4.13 (B1Y)
unnamed: RN3.8 (R1.2), U14.10 (B4Y)
unnamed: RN3.2 (R2.1), RN6.3 (R3.1), RN6.8 (R1.2)
unnamed: RN3.7 (R2.2), U14.11 (B3Y)
unnamed: RN3.3 (R3.1), RN6.4 (R4.1), RN6.6 (R3.2)
unnamed: RN3.6 (R3.2), U14.12 (B2Y)
unnamed: R3.1, RN3.4 (R4.1), RN6.5 (R4.2)
unnamed: RN3.5 (R4.2), U14.13 (B1Y)
unnamed: R13.2, U1.48 (K1)
unnamed: R6.2, U12.5 (CE)
unnamed: C4.1, U12.9 (CHROM_OUT)
unnamed: C2.1, U12.10 (CVBS_OUT)
unnamed: C5.1, U12.11 (LUM_OUT)
VCK+: RN8.3 (R3.1), U1.64 (H16)
VCK-: RN8.4 (R4.1), U1.65 (F15)
VD0+: RN8.1 (R1.1), U1.61 (C17)
VD0-: RN8.2 (R2.1), U1.62 (C18)
VD1+: RN9.3 (R3.1), U1.58 (F17)
VD1-: RN9.4 (R4.1), U1.59 (D18)
VD2+: RN9.1 (R1.1), U1.56 (G17)
VD2-: RN9.2 (R2.1), U1.55 (F18)

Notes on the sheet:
Signal output
Data Bus
4-bit DAC x 3
Timing (mixed direction)
Host Interface
Power Indicator
FPGA Interface
Video Output
Video Encoder (S-Vid and Composite)
Control Input

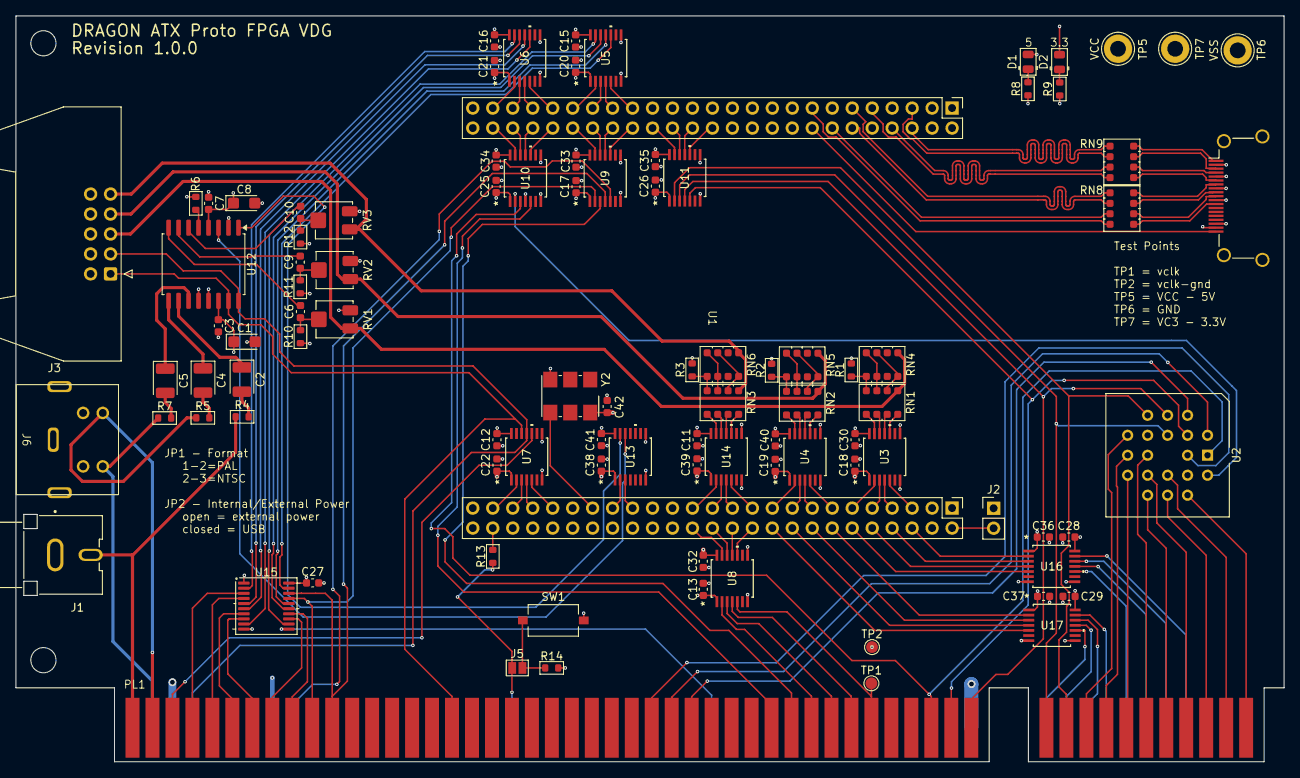
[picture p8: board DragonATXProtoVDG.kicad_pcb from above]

Board: 4 copper layers, 161.3 x 94.9 mm, 98 parts (0 on the bottom side), 172 nets.
